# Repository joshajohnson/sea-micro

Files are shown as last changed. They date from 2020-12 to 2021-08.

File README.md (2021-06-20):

# sea-micro

An Arduino Pro Micro, with but with a Type-C connector.

Targeted as an alternative for the ubiquitous Pro Micro in DIY keyboard applications.

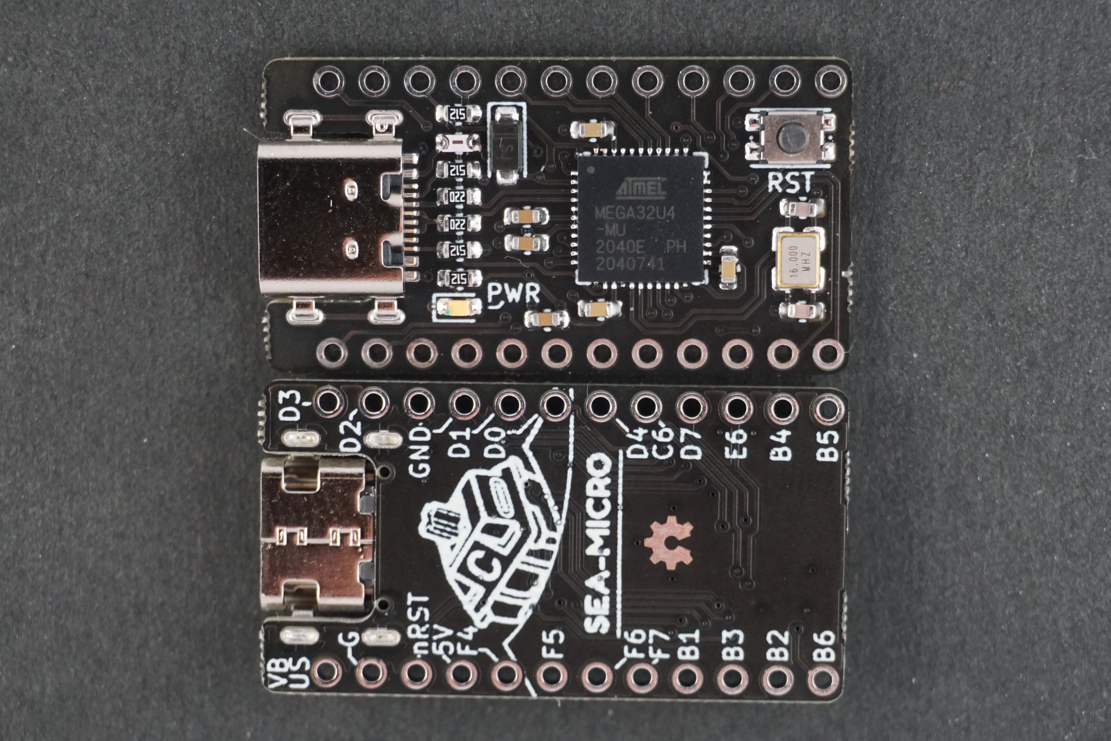
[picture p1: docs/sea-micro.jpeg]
sea-micro photo


Features:
- Pro Micro compatible pinout.
- Mid Mount USB Type-C Connector.
- On-board reset button.

Developed in conjunction with [Custom KBD](customkbd.com).

Revision History:

0.1 - "Elite-C" compatible pinout, with added ESD protection.

0.2 - Removes castellated pads for lower cost manufacturing.

0.3 - Name changed to sea-micro, now targeting Pro Micro w/ Type-C feature set at the lowest cost possible.

0.4 - Added D+ and D- pads on underside of PCB, DFM improvements for USB connector.

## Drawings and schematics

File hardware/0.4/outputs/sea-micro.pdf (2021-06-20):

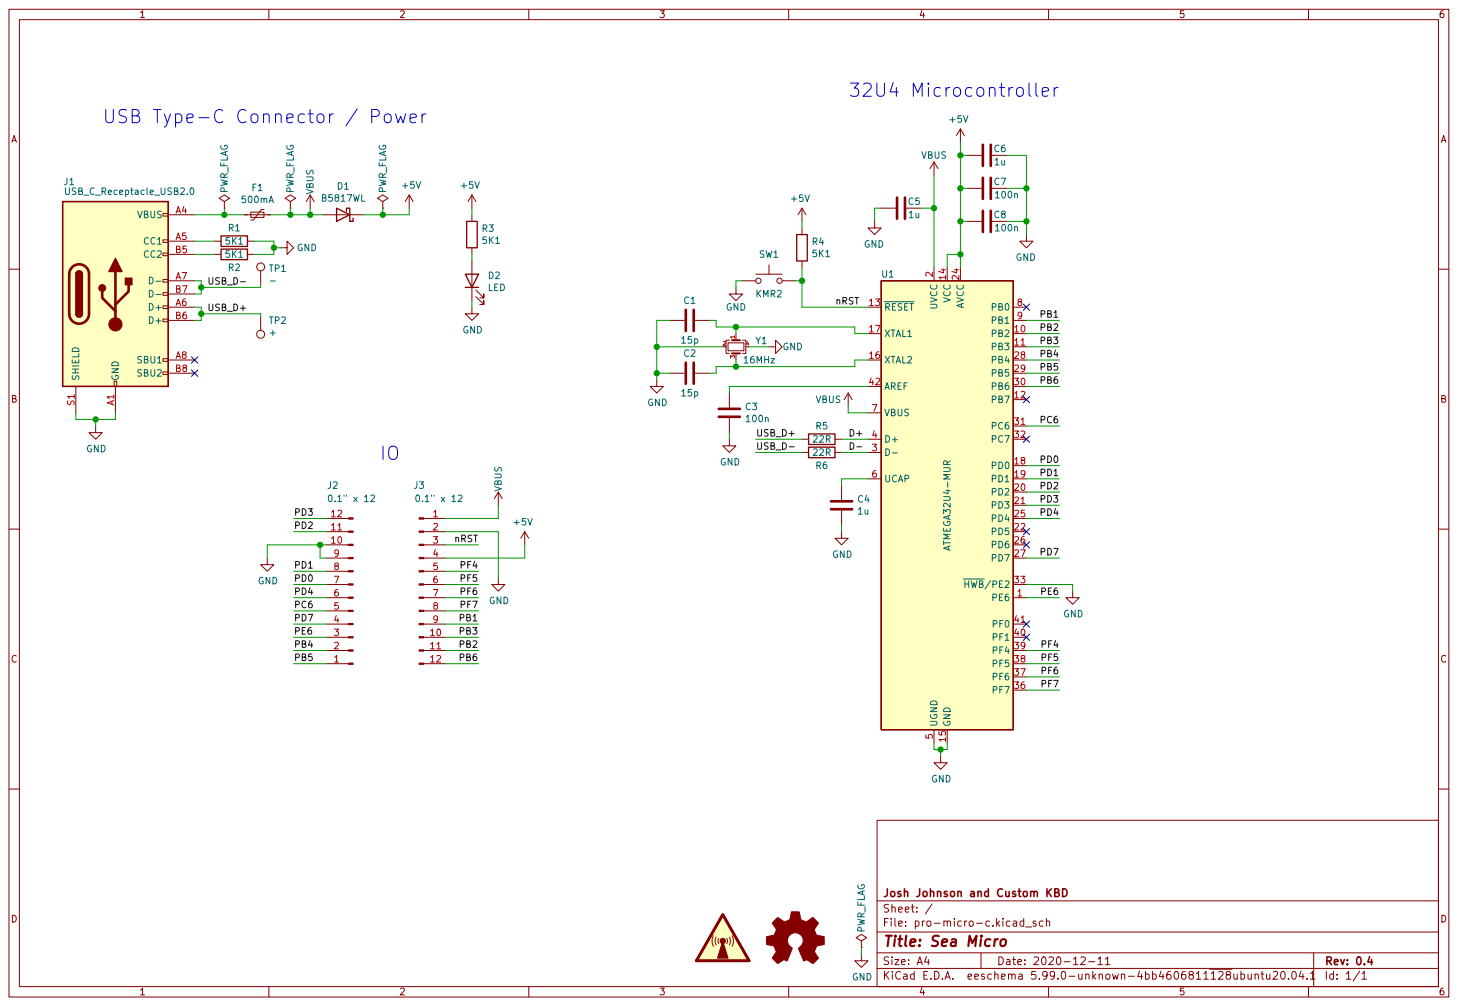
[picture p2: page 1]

2 PD2 20 PD3 21 PD5 22 AVCC 24 PD4 25 PD6 26 PD7 27 PB4 28 PB5 29 D- 3 PB6 30 PC6 31 PC7 32 ~HWB~/PE233 PF7 36 PF6 37 PF5 38 PF4 39 D+ 4 PF1 40 PF0 41 AREF 42 UGND

File: pro-micro-c.kicad_sch Sheet: / Josh Johnson and Custom KBD

Id: 1/1 Title: Sea Micro

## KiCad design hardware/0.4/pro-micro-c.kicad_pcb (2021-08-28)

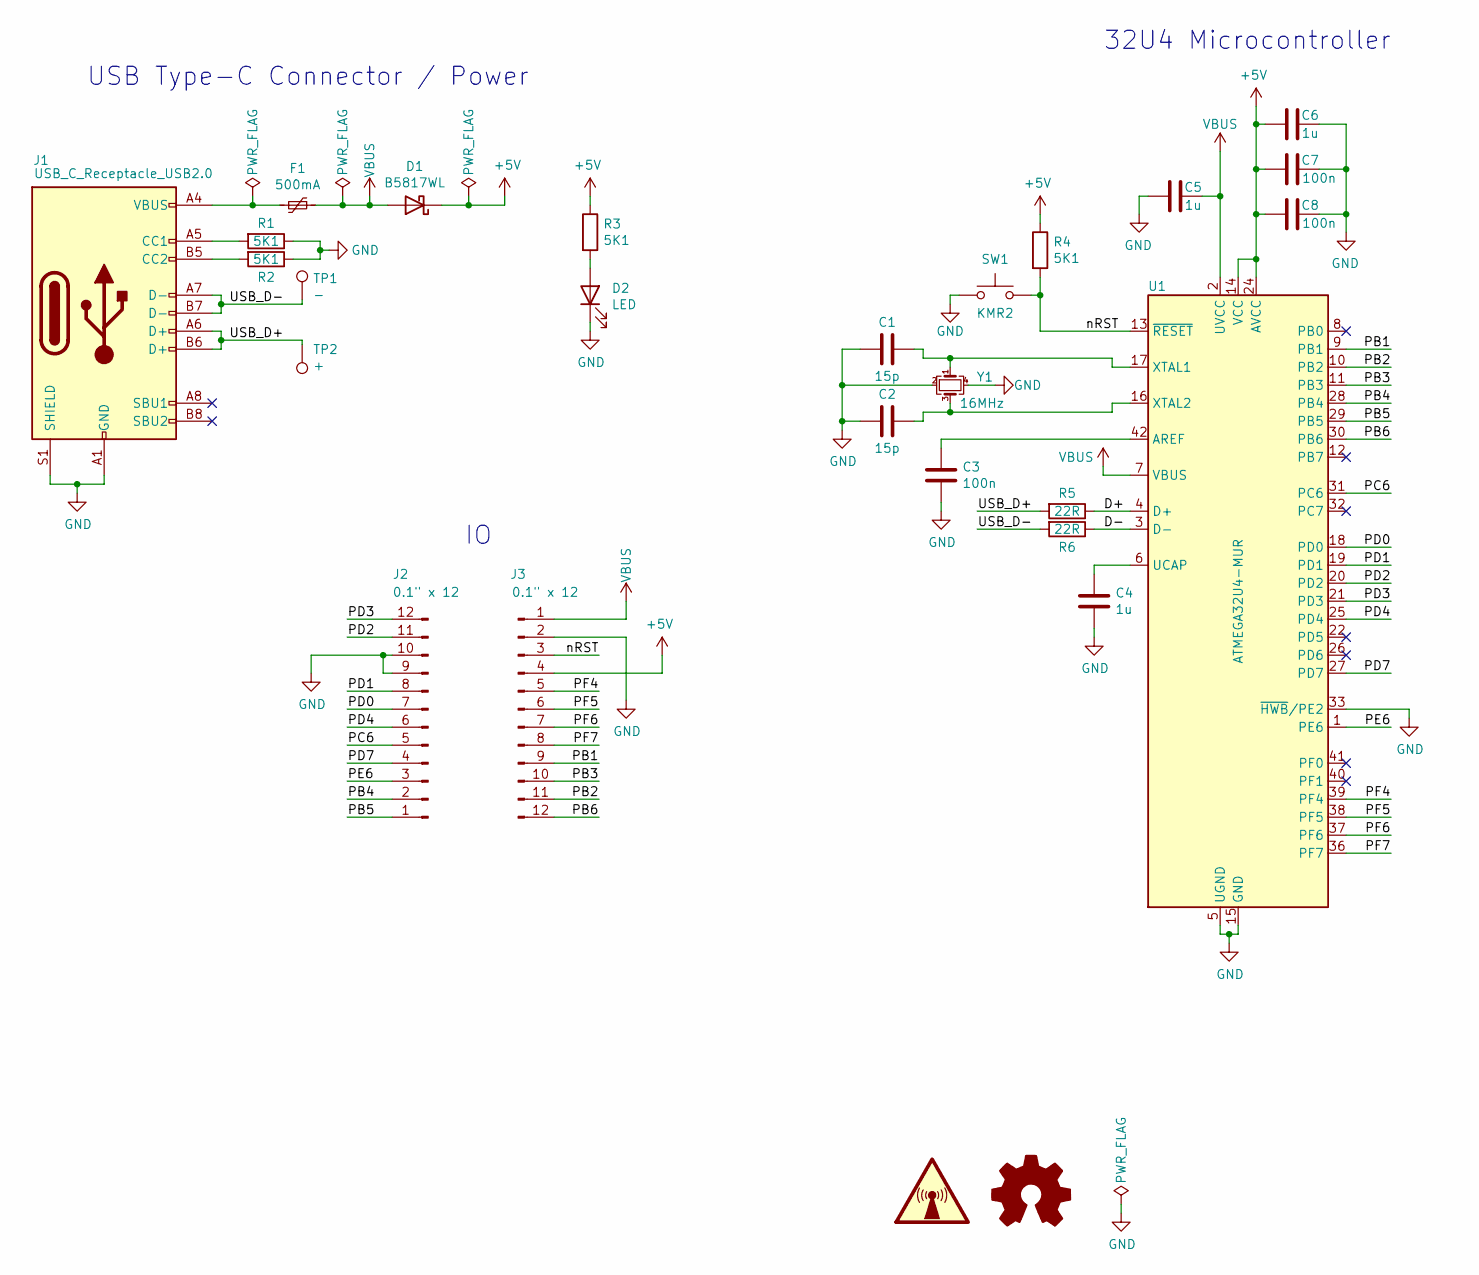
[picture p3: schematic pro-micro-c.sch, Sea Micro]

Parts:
C1, C2: 15p; C_0603_1608Metric; MPN CL10C150JB8NNNC; LCSC C1644
C3, C7, C8: 100n; C_0603_1608Metric; MPN CL10B104KO8NNNC; LCSC C66501
C4, C5, C6: 1u; C_0603_1608Metric; MPN CL10A105KO8NNNC; LCSC C1592
D1: B5817WL; D_SOD-123F; MPN B5817WL; LCSC C122853
D2: LED; LED_0603_1608Metric; MPN OSK40603C1E; LCSC C268294
F1: 500mA; Fuse_0603_1608Metric; MPN MF-FSMF050X-2; LCSC C210357
J1: USB_C_Receptacle_USB2.0; USB_C_TYPE-C-31-M-14; MPN TYPE-C-31-M-14; LCSC C223907
J2, J3: 0.1\" x 12; Castellated_Short_P2.54x12
LOGO1: Logo_Open_Hardware_Small; OSHW_Logo_3.6x3.6_F.Mask
R1, R2, R3, R4: 5K1; R_0603_1608Metric; MPN RC0603JR-075K1L; LCSC C14677
R5, R6: 22R; R_0603_1608Metric; MPN RC0603JR-0722RL; LCSC C108405
SW1: KMR2; SW_Push_KMR2; MPN TS-1185EC-C-D-B; LCSC C318893
SYM1: SYM_Radio_Waves_Large; sea-micro-silk
TP1: -; TestPoint_Pad_D1.5mm
TP2: +; TestPoint_Pad_D1.5mm
U1: ATMEGA32U4-MUR; QFN-44-1EP_7x7mm_P0.5mm_EP5.2x5.2mm; MPN ATMEGA32U4-MUR; LCSC C45874
Y1: 16MHz; Crystal_SMD_3225-4Pin_3.2x2.5mm; MPN TAXM16M4RDBCCT2T; LCSC C164044

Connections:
+5V: C6.1, C7.1, C8.1, D1.1 (K), J3.4, R3.1, R4.1, U1.14 (VCC), U1.24 (AVCC), U1.34 (VCC), U1.44 (AVCC)
/D+: R5.1, U1.4 (D+)
/D-: R6.1, U1.3 (D-)
/PB1: J3.9, U1.9 (PB1)
/PB2: J3.11, U1.10 (PB2)
/PB3: J3.10, U1.11 (PB3)
/PB4: J2.2, U1.28 (PB4)
/PB5: J2.1, U1.29 (PB5)
/PB6: J3.12, U1.30 (PB6)
/PC6: J2.5, U1.31 (PC6)
/PD0: J2.7, U1.18 (PD0)
/PD1: J2.8, U1.19 (PD1)
/PD2: J2.11, U1.20 (PD2)
/PD3: J2.12, U1.21 (PD3)
/PD4: J2.6, U1.25 (PD4)
/PD7: J2.4, U1.27 (PD7)
/PE6: J2.3, U1.1 (PE6)
/PF4: J3.5, U1.39 (PF4)
/PF5: J3.6, U1.38 (PF5)
/PF6: J3.7, U1.37 (PF6)
/PF7: J3.8, U1.36 (PF7)
/USB_D+: J1.A6 (D+), J1.B6 (D+), R5.2, TP2.1
/USB_D-: J1.A7 (D-), J1.B7 (D-), R6.2, TP1.1
/nRST: J3.3, R4.2, SW1.2, U1.13 (~RESET)
GND: C1.2, C2.2, C3.2, C4.2, C5.1, C6.2, C7.2, C8.2, D2.1 (K), J1.A1 (GND), J1.A12 (GND), J1.B1 (GND), J1.B12 (GND), J1.S1 (SHIELD), J2.9, J2.10, J3.2, R1.1, R2.1, SW1.1, U1.5 (UGND), U1.15 (GND), U1.23 (GND), U1.33 (~HWB~/PE2), U1.35 (GND), U1.43 (GND), U1.45 (GND), Y1.2, Y1.4
unnamed: C1.1, U1.17 (XTAL1), Y1.1
unnamed: C2.1, U1.16 (XTAL2), Y1.3
unnamed: C3.1, U1.42 (AREF)
unnamed: C4.1, U1.6 (UCAP)
unnamed: D2.2 (A), R3.2
unnamed: F1.2, J1.A4 (VBUS), J1.A9 (VBUS), J1.B4 (VBUS), J1.B9 (VBUS)
unnamed: J1.A5 (CC1), R1.2
unnamed: J1.B5 (CC2), R2.2
VBUS: C5.2, D1.2 (A), F1.1, J3.1, U1.2 (UVCC), U1.7 (VBUS)

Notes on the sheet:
32U4 Microcontroller
USB Type-C Connector / Power

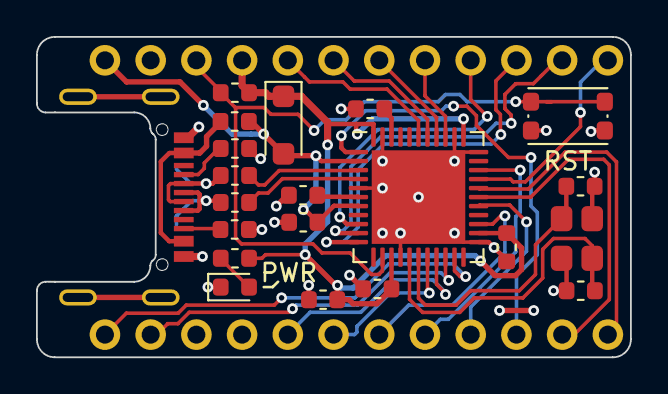
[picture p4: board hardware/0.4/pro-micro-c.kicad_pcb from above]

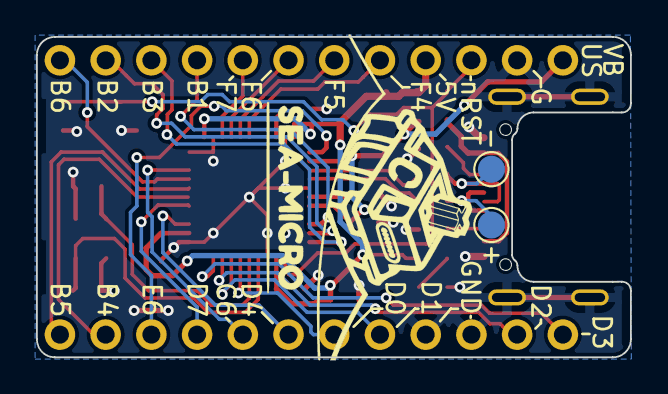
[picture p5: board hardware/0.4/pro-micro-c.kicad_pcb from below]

Board: 2 copper layers, 33.0 x 17.8 mm, 27 parts (4 on the bottom side), 34 nets.

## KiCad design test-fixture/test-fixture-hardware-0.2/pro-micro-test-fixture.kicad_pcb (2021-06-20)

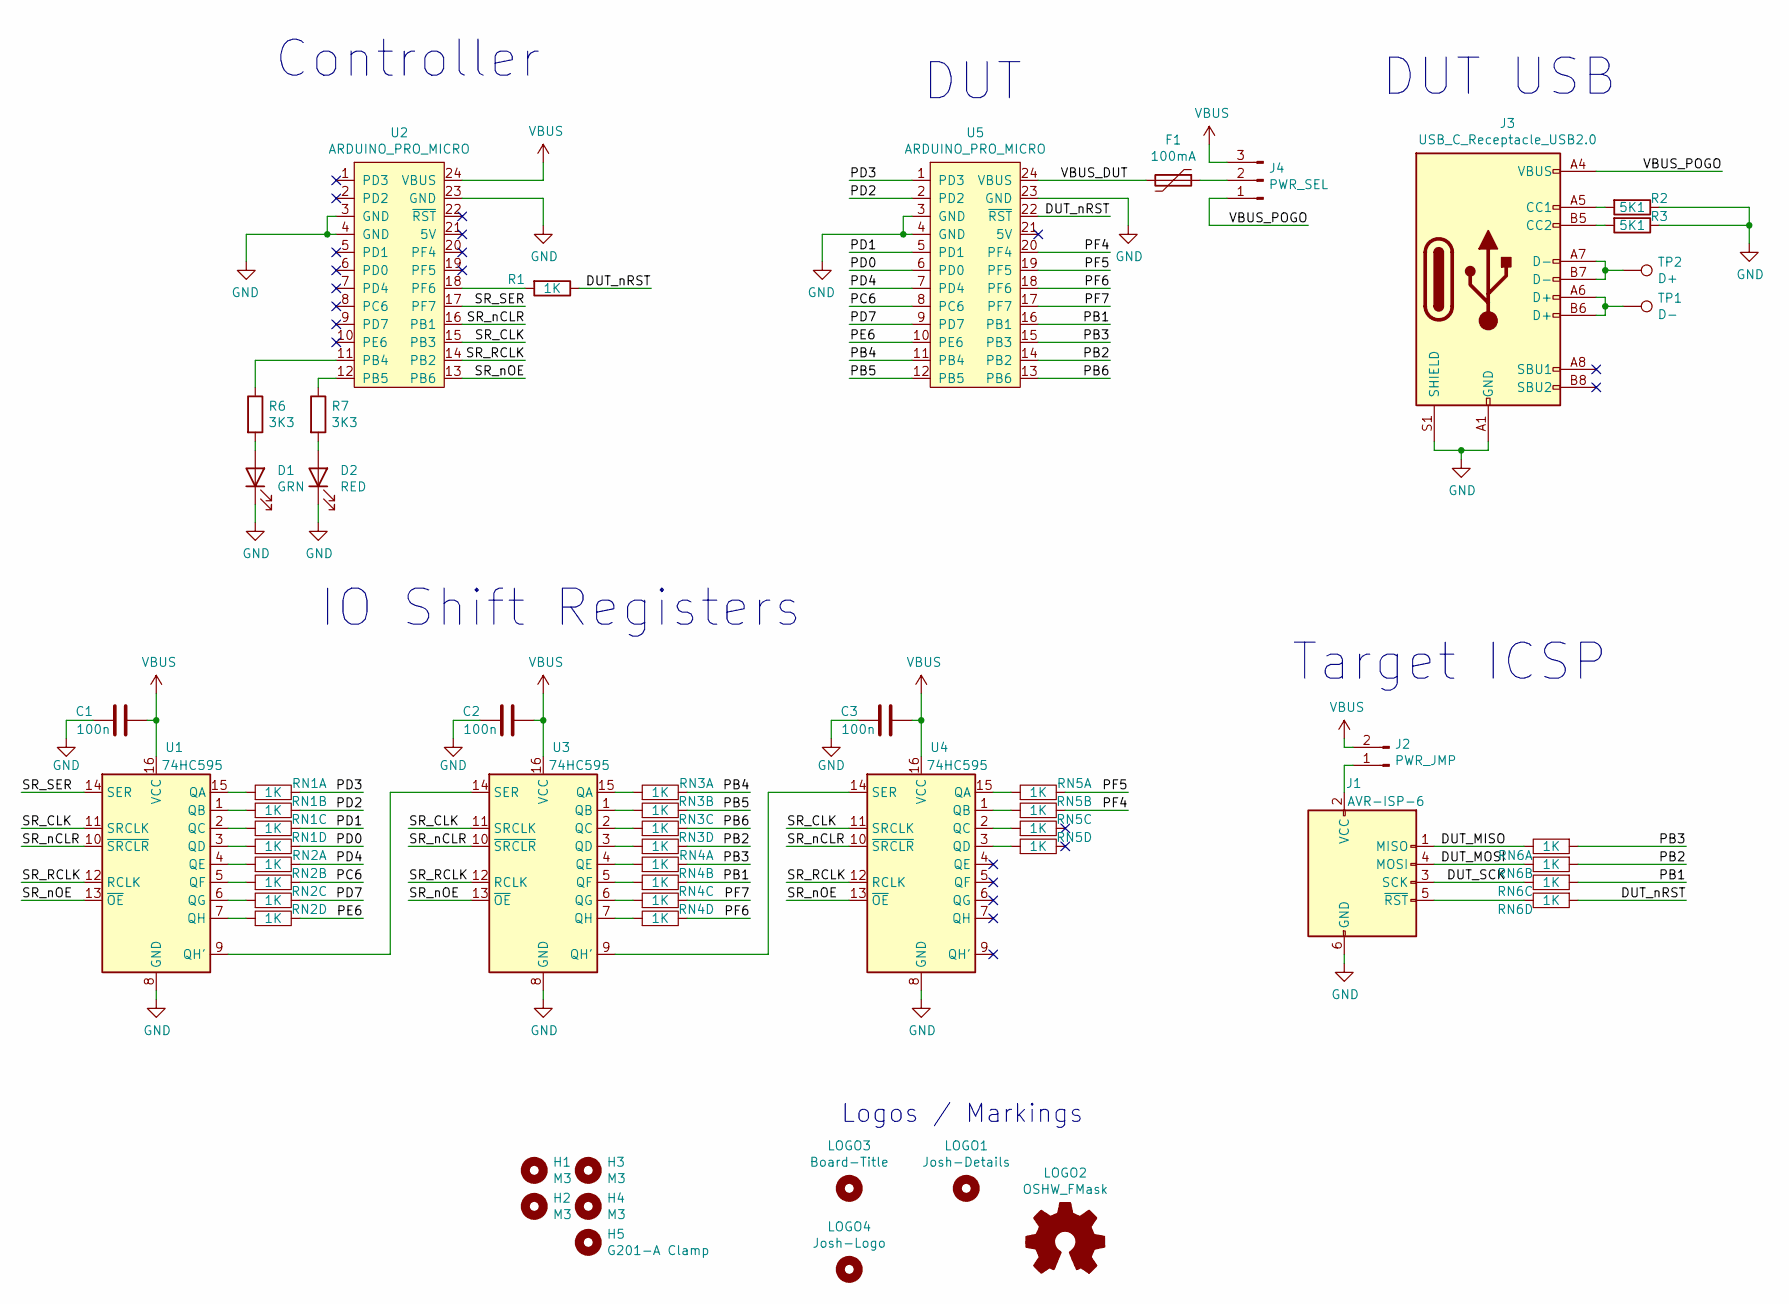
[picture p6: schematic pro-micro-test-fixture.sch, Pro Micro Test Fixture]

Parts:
C1, C2, C3: 100n; C_0603_1608Metric
D1: GRN; LED_0603_1608Metric
D2: RED; LED_0603_1608Metric
F1: 100mA; Fuse_0603_1608Metric
H1, H2, H3, H4: M3; MountingHole_3.2mm_M3_Pad
H5: G201-A Clamp; GH-201A
J1: AVR-ISP-6; IDC-Header_2x03_P2.54mm_Vertical
J2: PWR_JMP; PinHeader_1x02_P2.54mm_Vertical
J3: USB_C_Receptacle_USB2.0; USB_C_U262-161N-4BVC11
J4: PWR_SEL; PinHeader_1x03_P2.54mm_Horizontal
LOGO1: Josh-Details; josh-details
LOGO2: OSHW_FMask; OSHW_Logo_3.6x3.6_F.Mask
LOGO3: Board-Title; board-title
LOGO4: Josh-Logo; josh-johnson-logo-8_6x1_5
R1: 1K; R_0603_1608Metric
R2, R3: 5K1; R_0603_1608Metric
R6, R7: 3K3; R_0603_1608Metric
RN1, RN2, RN3, RN4, RN5, RN6: 1K; R_Array_Convex_4x0603
TP1: D-; TestPoint_Loop_D2.60mm_Drill1.4mm_Beaded
TP2: D+; TestPoint_Loop_D2.60mm_Drill1.4mm_Beaded
U1, U3, U4: 74HC595; SOIC-16_3.9x9.9mm_P1.27mm
U2: ARDUINO_PRO_MICRO; Arduino_Pro_Micro
U5: ARDUINO_PRO_MICRO; Arduino_Pro_Micro_POGO

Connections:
/DUT_MISO: J1.1 (MISO), RN6.5
/DUT_MOSI: J1.4 (MOSI), RN6.6
/DUT_SCK: J1.3 (SCK), RN6.7
/DUT_nRST: R1.1, RN6.1, U5.22 (~RST)
/PB1: RN4.6, RN6.2, U5.16 (PB1)
/PB2: RN3.8, RN6.3, U5.14 (PB2)
/PB3: RN4.5, RN6.4, U5.15 (PB3)
/PB4: RN3.5, U5.11 (PB4)
/PB5: RN3.6, U5.12 (PB5)
/PB6: RN3.7, U5.13 (PB6)
/PC6: RN2.6, U5.8 (PC6)
/PD0: RN1.8, U5.6 (PD0)
/PD1: RN1.7, U5.5 (PD1)
/PD2: RN1.6, U5.2 (PD2)
/PD3: RN1.5, U5.1 (PD3)
/PD4: RN2.5, U5.7 (PD4)
/PD7: RN2.7, U5.9 (PD7)
/PE6: RN2.8, U5.10 (PE6)
/PF4: RN5.6, U5.20 (PF4)
/PF5: RN5.5, U5.19 (PF5)
/PF6: RN4.8, U5.18 (PF6)
/PF7: RN4.7, U5.17 (PF7)
/SR_CLK: U1.11 (SRCLK), U2.15 (PB3), U3.11 (SRCLK), U4.11 (SRCLK)
/SR_RCLK: U1.12 (RCLK), U2.14 (PB2), U3.12 (RCLK), U4.12 (RCLK)
/SR_SER: U1.14 (SER), U2.17 (PF7)
/SR_nCLR: U1.10 (~SRCLR), U2.16 (PB1), U3.10 (~SRCLR), U4.10 (~SRCLR)
/SR_nOE: U1.13 (~OE), U2.13 (PB6), U3.13 (~OE), U4.13 (~OE)
/VBUS_DUT: F1.2, U5.24 (VBUS)
/VBUS_POGO: J3.A4 (VBUS), J3.A9 (VBUS), J3.B4 (VBUS), J3.B9 (VBUS), J4.1
GND: C1.2, C2.2, C3.2, D1.1 (K), D2.1 (K), J1.6 (GND), J3.A1 (GND), J3.A12 (GND), J3.B1 (GND), J3.B12 (GND), J3.S1 (SHIELD), R2.1, R3.1, U1.8 (GND), U2.3 (GND), U2.4 (GND), U2.23 (GND), U3.8 (GND), U4.8 (GND), U5.3 (GND), U5.4 (GND), U5.23 (GND)
unnamed: D1.2 (A), R6.2
unnamed: D2.2 (A), R7.2
unnamed: F1.1, J4.2
unnamed: J1.2 (VCC), J2.1
unnamed: J1.5 (~RST), RN6.8
unnamed: J3.A5 (CC1), R2.2
unnamed: J3.A6 (D+), J3.B6 (D+), TP1.1
unnamed: J3.A7 (D-), J3.B7 (D-), TP2.1
unnamed: J3.B5 (CC2), R3.2
unnamed: R1.2, U2.18 (PF6)
unnamed: R6.1, U2.11 (PB4)
unnamed: R7.1, U2.12 (PB5)
unnamed: RN1.1, U1.3 (QD)
unnamed: RN1.2, U1.2 (QC)
unnamed: RN1.3, U1.1 (QB)
unnamed: RN1.4, U1.15 (QA)
unnamed: RN2.1, U1.7 (QH)
unnamed: RN2.2, U1.6 (QG)
unnamed: RN2.3, U1.5 (QF)
unnamed: RN2.4, U1.4 (QE)
unnamed: RN3.1, U3.3 (QD)
unnamed: RN3.2, U3.2 (QC)
unnamed: RN3.3, U3.1 (QB)
unnamed: RN3.4, U3.15 (QA)
unnamed: RN4.1, U3.7 (QH)
unnamed: RN4.2, U3.6 (QG)
unnamed: RN4.3, U3.5 (QF)
unnamed: RN4.4, U3.4 (QE)
unnamed: RN5.1, U4.3 (QD)
unnamed: RN5.2, U4.2 (QC)
unnamed: RN5.3, U4.1 (QB)
unnamed: RN5.4, U4.15 (QA)
unnamed: U1.9 (QH'), U3.14 (SER)
unnamed: U3.9 (QH'), U4.14 (SER)
VBUS: C1.1, C2.1, C3.1, J2.2, J4.3, U1.16 (VCC), U2.24 (VBUS), U3.16 (VCC), U4.16 (VCC)

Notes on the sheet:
Logos / Markings
Controller
DUT
IO Shift Registers
Target ICSP
DUT USB

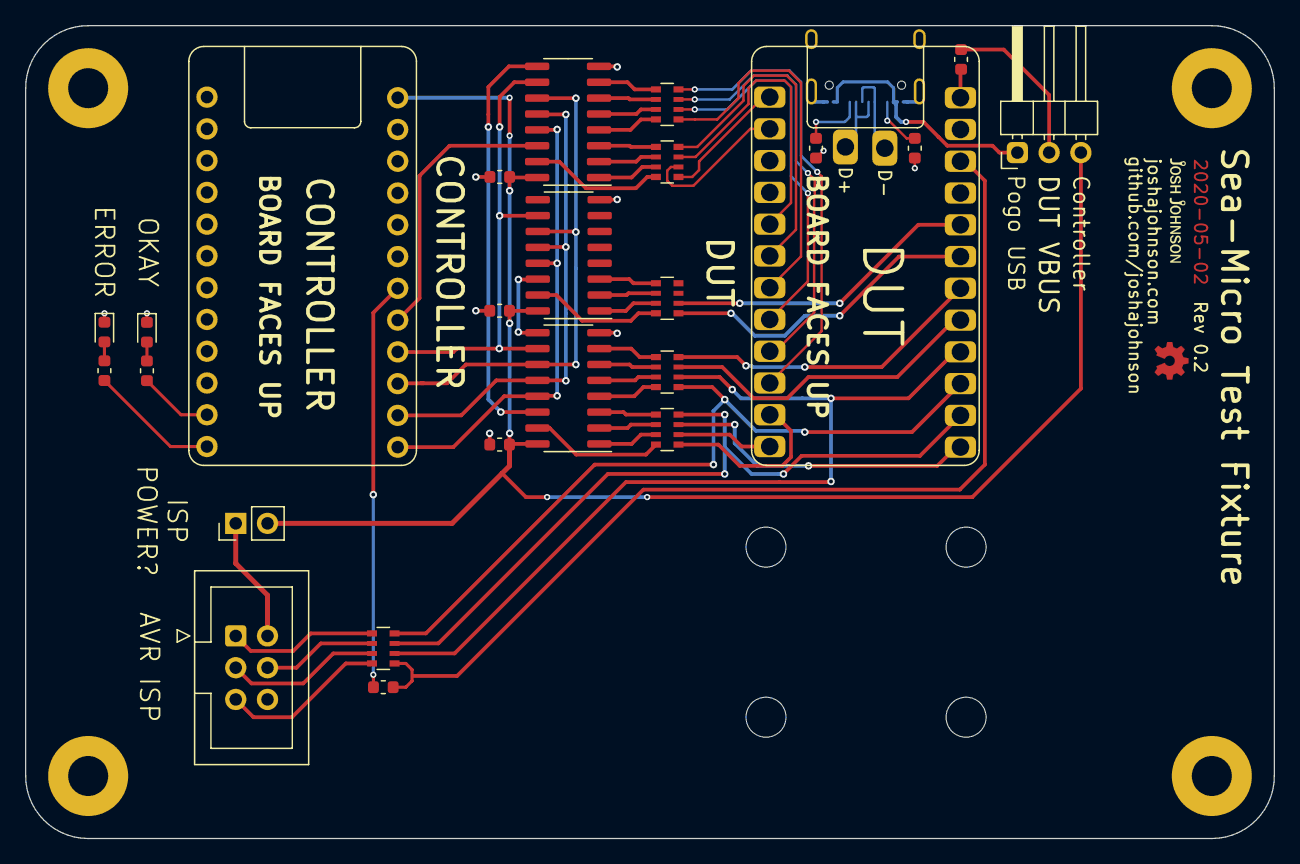
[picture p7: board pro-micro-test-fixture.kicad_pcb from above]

Board: 2 copper layers, 99.8 x 65.0 mm, 39 parts (1 on the bottom side), 65 nets.

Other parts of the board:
LOGO2#2: OSHW_FMask; OSHW_Logo_3.6x3.6_F.Mask
LOGO3#2: Board-Title; board-title

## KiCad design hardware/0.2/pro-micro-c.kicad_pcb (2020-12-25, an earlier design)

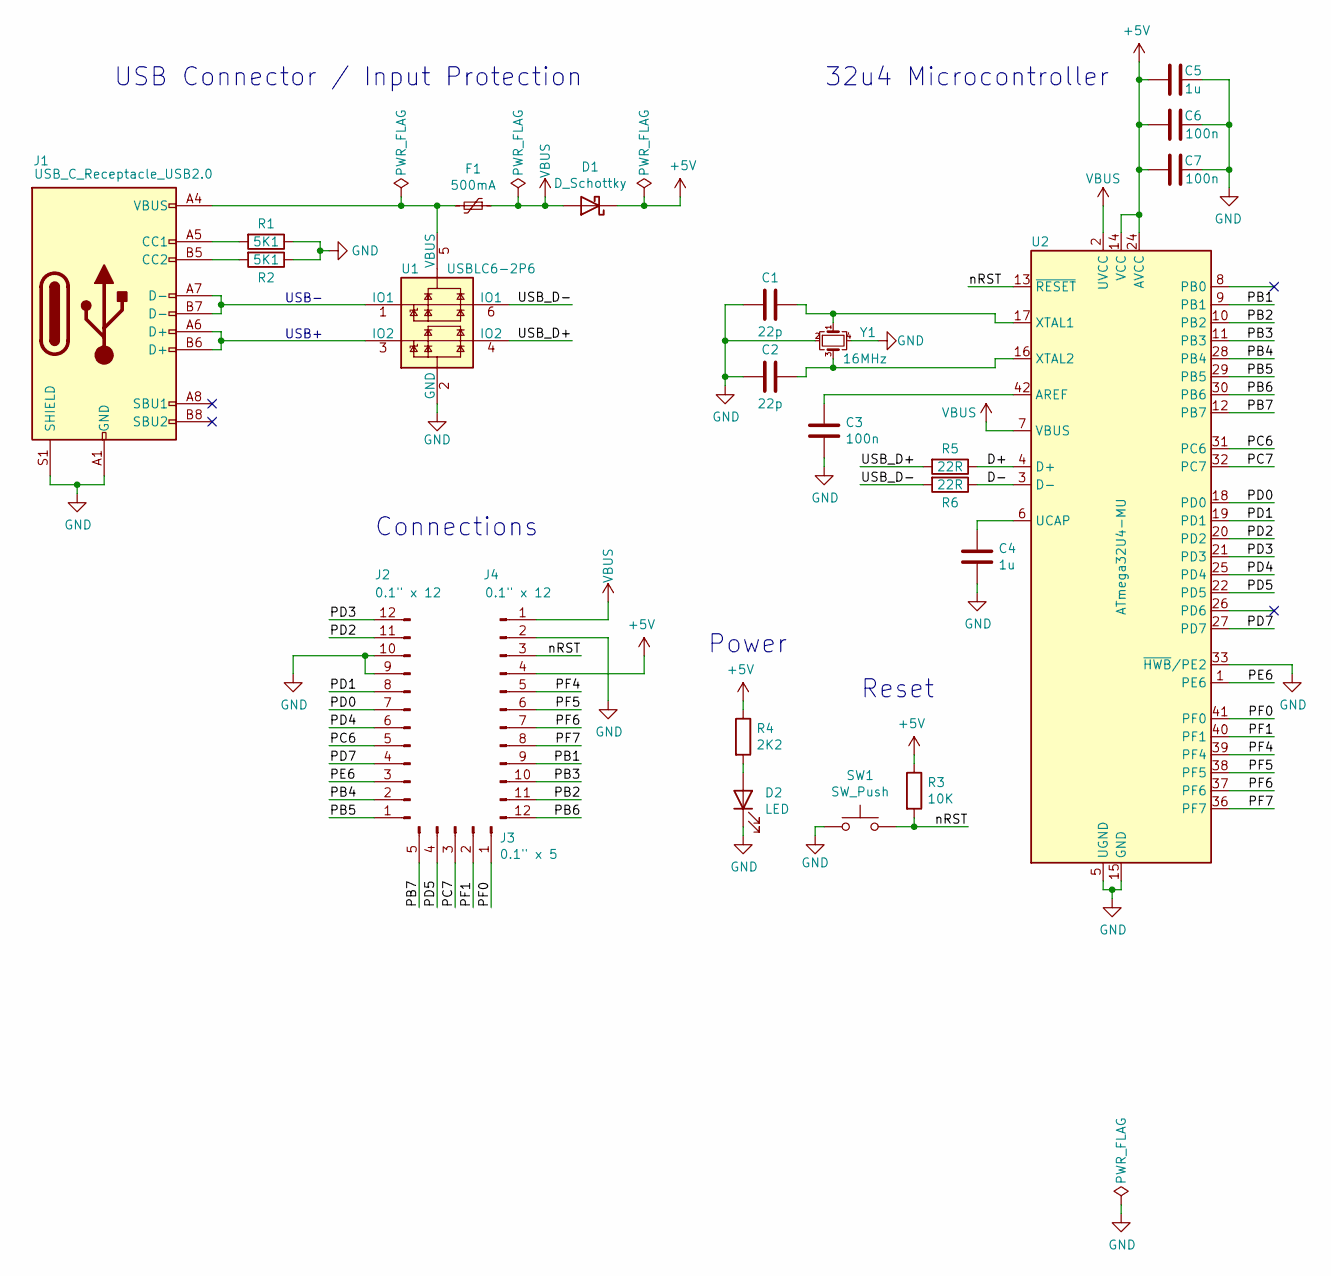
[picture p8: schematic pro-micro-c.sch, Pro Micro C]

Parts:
C1, C2: 22p; C_0402_1005Metric
C3, C6, C7: 100n; C_0402_1005Metric
C4, C5: 1u; C_0402_1005Metric
D1: D_Schottky; D_SOD-123F
D2: LED; LED_0603_1608Metric_Castellated
F1: 500mA; Fuse_0603_1608Metric
J1: USB_C_Receptacle_USB2.0; USB_C_TYPE-C-31-M-14
J2, J4: 0.1\" x 12; Castellated_Short_P2.54x12
J3: 0.1\" x 5; Castellated_Short_2.54x5
R1, R2: 5K1; R_0402_1005Metric
R3: 10K; R_0402_1005Metric
R4: 2K2; R_0402_1005Metric
R5, R6: 22R; R_0402_1005Metric
SW1: SW_Push; SW_Push_1P1T_NO_CK_KMR2
U1: USBLC6-2P6; SOT-666
U2: ATmega32U4-MU; QFN-44-1EP_7x7mm_P0.5mm_EP5.2x5.2mm
Y1: 16MHz; Crystal_SMD_3225-4Pin_3.2x2.5mm

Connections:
+5V: C5.1, C6.1, C7.1, D1.1 (K), J4.4, R3.1, R4.1, U2.14 (VCC), U2.24 (AVCC), U2.34 (VCC), U2.44 (AVCC)
/D+: R5.1, U2.4 (D+)
/D-: R6.1, U2.3 (D-)
/PB1: J4.9, U2.9 (PB1)
/PB2: J4.11, U2.10 (PB2)
/PB3: J4.10, U2.11 (PB3)
/PB4: J2.2, U2.28 (PB4)
/PB5: J2.1, U2.29 (PB5)
/PB6: J4.12, U2.30 (PB6)
/PB7: J3.5, U2.12 (PB7)
/PC6: J2.5, U2.31 (PC6)
/PC7: J3.3, U2.32 (PC7)
/PD0: J2.7, U2.18 (PD0)
/PD1: J2.8, U2.19 (PD1)
/PD2: J2.11, U2.20 (PD2)
/PD3: J2.12, U2.21 (PD3)
/PD4: J2.6, U2.25 (PD4)
/PD5: J3.4, U2.22 (PD5)
/PD7: J2.4, U2.27 (PD7)
/PE6: J2.3, U2.1 (PE6)
/PF0: J3.1, U2.41 (PF0)
/PF1: J3.2, U2.40 (PF1)
/PF4: J4.5, U2.39 (PF4)
/PF5: J4.6, U2.38 (PF5)
/PF6: J4.7, U2.37 (PF6)
/PF7: J4.8, U2.36 (PF7)
/USB_D+: R5.2, U1.4 (IO2)
/USB_D-: R6.2, U1.6 (IO1)
/nRST: J4.3, R3.2, SW1.2, U2.13 (~RESET)
GND: C1.2, C2.2, C3.2, C4.2, C5.2, C6.2, C7.2, D2.1 (K), J1.A1 (GND), J1.A12 (GND), J1.B1 (GND), J1.B12 (GND), J1.S1 (SHIELD), J2.9, J2.10, J4.2, R1.1, R2.1, SW1.1, U1.2 (GND), U2.5 (UGND), U2.15 (GND), U2.23 (GND), U2.33 (~HWB~/PE2), U2.35 (GND), U2.43 (GND), U2.45 (GND), Y1.2, Y1.4
unnamed: C1.1, U2.17 (XTAL1), Y1.1
unnamed: C2.1, U2.16 (XTAL2), Y1.3
unnamed: C3.1, U2.42 (AREF)
unnamed: C4.1, U2.6 (UCAP)
unnamed: D2.2 (A), R4.2
unnamed: F1.2, J1.A4 (VBUS), J1.A9 (VBUS), J1.B4 (VBUS), J1.B9 (VBUS), U1.5 (VBUS)
unnamed: J1.A5 (CC1), R1.2
unnamed: J1.A6 (D+), J1.B6 (D+), U1.3 (IO2)
unnamed: J1.A7 (D-), J1.B7 (D-), U1.1 (IO1)
unnamed: J1.B5 (CC2), R2.2
VBUS: D1.2 (A), F1.1, J4.1, U2.2 (UVCC), U2.7 (VBUS)

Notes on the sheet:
Reset
32u4 Microcontroller
USB Connector / Input Protection
Connections
Power
USB+
USB-

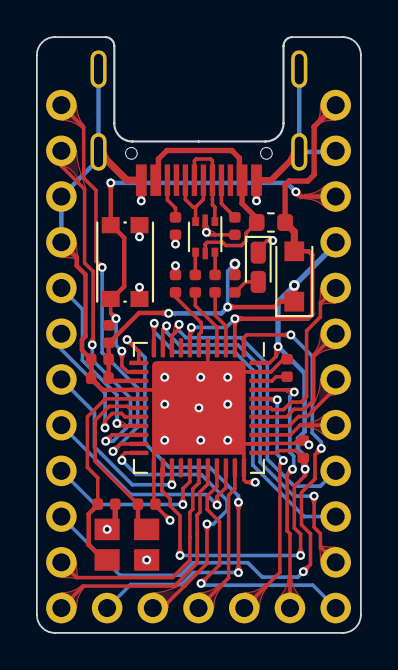
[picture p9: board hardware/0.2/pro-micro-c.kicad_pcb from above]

Board: 2 copper layers, 18.0 x 33.1 mm, 24 parts (0 on the bottom side), 41 nets.

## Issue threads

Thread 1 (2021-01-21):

BOM part number

musakajima, 2021-01-21:
hi josh,

I wanna try to make your version usb c pro micro version for my redox keyboard, already list material from your assembly file but i don't have any clue to get the right components.
do you mind to give detail references for the components (part number)? i wanna source them from lcsc

joshajohnson, 2021-01-21:
I have exported the BOM from EESchema and is can be found [here](https://github.com/joshajohnson/sea-micro/blob/master/hardware/0.3/outputs/bom.csv).

Closed 2021-01-21.

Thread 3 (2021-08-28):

Lines in error layer in v0.4.

OrvilleQ, 2021-08-28:
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

This happend because lines locate at (122, 94) and (124, 102) are in the wrong layer.

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

They should in Edge.Cuts.

I'm making a patch now, will open a pull request soon.

joshajohnson, 2021-08-28:
Thanks for catching this, happy to fix it myself if you've got other things to do, otherwise will happily merge the PR :)

OrvilleQ, 2021-08-28:
Pull request has opend.

I am new to PCB design, and I'm learning how to deal with ATMEGA32U4 from your project now.

Happy to help with you and thanks for making this project.

joshajohnson, 2021-08-28:
Resolved in https://github.com/joshajohnson/sea-micro/pull/4.

Thanks for the fix!

Closed 2021-08-28.

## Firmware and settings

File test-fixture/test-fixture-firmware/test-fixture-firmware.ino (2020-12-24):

// 74HC595 Pins
#define SR_nOE  10  // B6
#define SR_SER  18  // F7
#define SR_CLK  14  // B3
#define SR_RCLK 16  // B2
#define SR_nCLR 15  // B1

// DUT Reset
#define DUT_nRST  19  // F6

// State LEDs
#define LED_OKAY  8   // B4
#define LED_ERROR 9   // B5

// Commands
#define STATE_OKAY  32
#define STATE_ERROR 33
#define STATE_RESET 34

#define HIGH_Z      128
#define HARD_RESET  255

void shift_out(uint16_t upper, uint16_t bs_lower);
void press_key(uint8_t key);

void setup() 
{
  // Shift Reg
  pinMode(SR_nOE, OUTPUT);
  pinMode(SR_SER, OUTPUT);
  pinMode(SR_nCLR, OUTPUT);
  pinMode(SR_CLK, OUTPUT);
  pinMode(SR_RCLK, OUTPUT);

  digitalWrite(SR_nCLR, HIGH);
  shift_out(0xFFFF, 0xFFFF); // Init High
  digitalWrite(SR_nOE, LOW);

  // DUT nRST start high
  pinMode(DUT_nRST, OUTPUT);
  digitalWrite(DUT_nRST, HIGH);

  // LEDs
  pinMode(LED_OKAY, OUTPUT);
  pinMode(LED_ERROR, OUTPUT);

  Serial.begin(115200);
}

void loop() 
{
  while (Serial.available() > 0)
  {
    int data = Serial.parseInt();

    if (data >= 1 && data <= 18)
    {
      press_key(data);
    }
    else if (data == HIGH_Z)
    {
      digitalWrite(SR_nOE, HIGH);
      digitalWrite(DUT_nRST, HIGH);
      pinMode(DUT_nRST, INPUT);
      Serial.println("High Z IO");
    }
    else if (data == STATE_OKAY)
    {
      digitalWrite(LED_ERROR, LOW);
      digitalWrite(LED_OKAY, HIGH);
      Serial.println("State OKAY");
    }
    else if (data == STATE_ERROR)
    {
      digitalWrite(LED_ERROR, HIGH);
      digitalWrite(LED_OKAY, LOW);
      Serial.println("State ERROR");
    }
    else if (data == STATE_RESET)
    {
      digitalWrite(LED_ERROR, LOW);
      digitalWrite(LED_OKAY, LOW);
      Serial.println("State RESET");
    }
    else if (data == HARD_RESET)
    {
      pinMode(DUT_nRST, OUTPUT);
      digitalWrite(DUT_nRST, LOW);
      delay(1);
      digitalWrite(DUT_nRST, HIGH);
      Serial.println("Hard Reset DUT");
    }
  }
}

void press_key(uint8_t key)
{
  uint16_t bs_upper = key > 16 ? ~(1 << ((key-16) - 1)) : 0xFFFF;
  uint16_t bs_lower = key <= 16  ? ~(1 << (key - 1)) : 0xFFFF;

  shift_out(bs_upper, bs_lower); // 24 bits, active low, MSB first
  delay(50);
  shift_out(0xFFFF, 0xFFFF); // Release all keys
  delay(1);

  Serial.print("Pressed Key: ");
  Serial.println(key, DEC);
}

void shift_out(uint16_t upper, uint16_t lower)
{
  Serial.print(upper, BIN);
  Serial.println(lower, BIN);

  // Shift out 24 bits, MSB first
  digitalWrite(SR_RCLK, LOW);
  shiftOut(SR_SER, SR_CLK, MSBFIRST, (upper & 0xFF));           // third byte (MSB)
  shiftOut(SR_SER, SR_CLK, MSBFIRST, (lower & 0xFF00) >> 8);    // second byte
  shiftOut(SR_SER, SR_CLK, MSBFIRST, (lower & 0xFF));           // first byte (LSB)
  digitalWrite(SR_RCLK, HIGH);
}

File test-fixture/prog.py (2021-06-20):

#!/bin/python3

# Script to program and test sea-micro

import os
import time
import argparse
from colorama import Fore
import serial
from serial.tools import list_ports
import io
from multiprocessing import Process

def bootloader():
    ''' Flashes bootloader using an external programmer connected to the ISP port on the test fixture.
        Defaults to AVRISPMKII, but can be used with a usbasp by changing the arg to -c.'''
    global mcu_reset
    mcu_reset = True

    bootloader = "avrdude -C avrdude.conf -v -p atmega32u4 -c avrispmkii -P usb -U flash:w:bootloader_atmega32u4.hex:i -U lfuse:w:0x5E:m -U hfuse:w:0xD9:m -U efuse:w:0xC3:m -F"
    
    retval = os.system(bootloader)

    if retval != 0:
        send_string(33) # Error
        print(f'{Fore.RED}#############################')
        print(f'{Fore.RED}FAIL AT WRITING BOOTLOADER!!!')
        print(f'{Fore.RED}#############################')
        exit()

    print(f'{Fore.BLUE}BOOTLOADER FLASHED{Fore.WHITE}')

def flash_firmware():
    ''' Flashes test firmware. Assumes atmel-dfu bootloader is already flashed to board. '''
    global mcu_reset

    if mcu_reset == False:
        send_string(255) # Hard reset
        mcu_reset = True
        time.sleep(2)

    erase = "dfu-programmer atmega32u4 erase"
    flash = "dfu-programmer atmega32u4 flash sea_micro_test.hex"
    reset = "dfu-programmer atmega32u4 reset"

    print(f'{Fore.BLUE}ERASING DUT{Fore.WHITE}')
    retval = os.system(erase)

    if retval == 0:
        print(f'{Fore.BLUE}FLASHING DUT{Fore.WHITE}')
        retval = os.system(flash)

    if retval == 0:
        print(f'{Fore.BLUE}RESETTING DUT{Fore.WHITE}')
        mcu_reset = True
        retval = os.system(reset)

    if (retval != 0) and (retval != 256): # For some reason the reset retval is 256 on success in some cases
        send_string(33) # Error
        print(f'{Fore.RED}############################')
        print(f'{Fore.RED}FAIL AT FLASHING TEST FW !!!')
        print(f'{Fore.RED}############################')
        exit()

    print(f'{Fore.BLUE}TEST FIRMWARE FLASHED{Fore.WHITE}')

def send_string(string):
    serial_io.write(str(string) + "\r\n")
    serial_io.flush()

def test_keys():
    ''' Test all IO with test fixture.
        Transmit number according to pin location, which test fixture will pull low, simulating key press.
        DUT will then respond with the alpha character (A=1, B=2 etc) which we can check. '''
    global mcu_reset

    # Ensure board is out of reset
    if (mcu_reset == False):
        print(f'{Fore.BLUE}ENSURING 32U4 READY{Fore.WHITE}')
        os.system("dfu-programmer atmega32u4 reset")
        time.sleep(1)

    for char in range(1,19): # sea-micro has 18 IO

        alpha = chr(96 + char)

        # Transmit required char, and compare to what we want
        send_string(char)

        recv = input()
        print(f'Requested: {alpha} Received: {str(recv)}')

        if recv != alpha: # retry once

            print("Trying Again!")
            send_string(char)

            recv = input()
            print(f'Requested: {alpha} Received: {str(recv)}') 

            if recv != alpha:
                send_string(33) # Error
                print(f'{Fore.RED}###############')
                print(f'{Fore.RED}NOT TYPING {alpha} !!!')
                print(f'{Fore.RED}###############')
                exit()

    print(f'{Fore.BLUE}KEYS TEST PASSED{Fore.WHITE}')

if __name__ == "__main__":

    # Connect to test fixture
    serial_io = None
    uart = serial.Serial("/dev/ttyACM0", 115200, timeout=0.1)
    serial_io = io.TextIOWrapper(io.BufferedRWPair(uart, uart))

    # State if board is fresh or already has test FW on there
    mcu_reset = False

    parser = argparse.ArgumentParser()
    parser.add_argument("-b", "--bootloader",   action='store_true')
    parser.add_argument("-f", "--firmware",     action='store_true')
    parser.add_argument("-t", "--test",         action='store_true')
    args = parser.parse_args()

    send_string(34) # Reset status LEDs

    if args.bootloader:
        bootloader()
        time.sleep(2)
    if args.firmware:
        flash_firmware()
        time.sleep(2)
    if args.test:
        test_keys()        

    send_string(32) # Status OKAY
    print(f'{Fore.GREEN}###################')
    print(f'{Fore.GREEN}ALL STEPS PASSED!!!')
    print(f'{Fore.GREEN}###################{Fore.WHITE}')

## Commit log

2020-01-08 layout done
    [pro-micro-c.kicad_pcb, pro-micro-c.sch]
2020-07-26 update files + readme
    [pro-micro-c.kicad_pcb, pro-micro-c.sch]
2020-12-11 all nets routed
    [pro-micro-c.kicad_pcb, pro-micro-c.sch]
2020-12-11 layout looking good
    [pro-micro-c.kicad_pcb, pro-micro-c.sch]
2020-12-11 BOM complete + cleaning up traces
    [pro-micro-c.kicad_pcb, pro-micro-c.sch]
2020-12-12 add silk
    [pro-micro-c.kicad_pcb, pro-micro-c.sch]
2020-12-13 v0.3 and test fixture off to fab
    [pro-micro-c-panel.kicad_pcb, pro-micro-c.step, pro-micro-test-fixture.kicad_pcb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]
2020-12-23 test fixture sw/fw, untested
    [pro-micro-c.step, pro-micro-test-fixture.kicad_pcb, pro-micro-test-fixture.sch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]
2020-12-25 clean up repo inc rename
    [pro-micro-c.kicad_pcb, pro-micro-c.sch, pro-micro-test-fixture.kicad_pcb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]
2021-01-06 add pdf of schematic
2021-01-21 update output files
    [bom.csv, pro-micro-c-panel.kicad_pcb]
2021-02-26 export 3d model
    [sea-micro.step]
2021-06-20 update test fixtures
    [pro-micro-test-fixture.kicad_pcb, pro-micro-test-fixture.sch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]
2021-06-20 release 0.4
    [bom.csv, pro-micro-c.kicad_pcb, pro-micro-c.sch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]
2021-06-20 update docs
    [pro-micro-test-fixture.kicad_pcb, pro-micro-test-fixture.sch]
2021-08-28 fix usb c connector outline
    [pro-micro-c.kicad_pcb]
